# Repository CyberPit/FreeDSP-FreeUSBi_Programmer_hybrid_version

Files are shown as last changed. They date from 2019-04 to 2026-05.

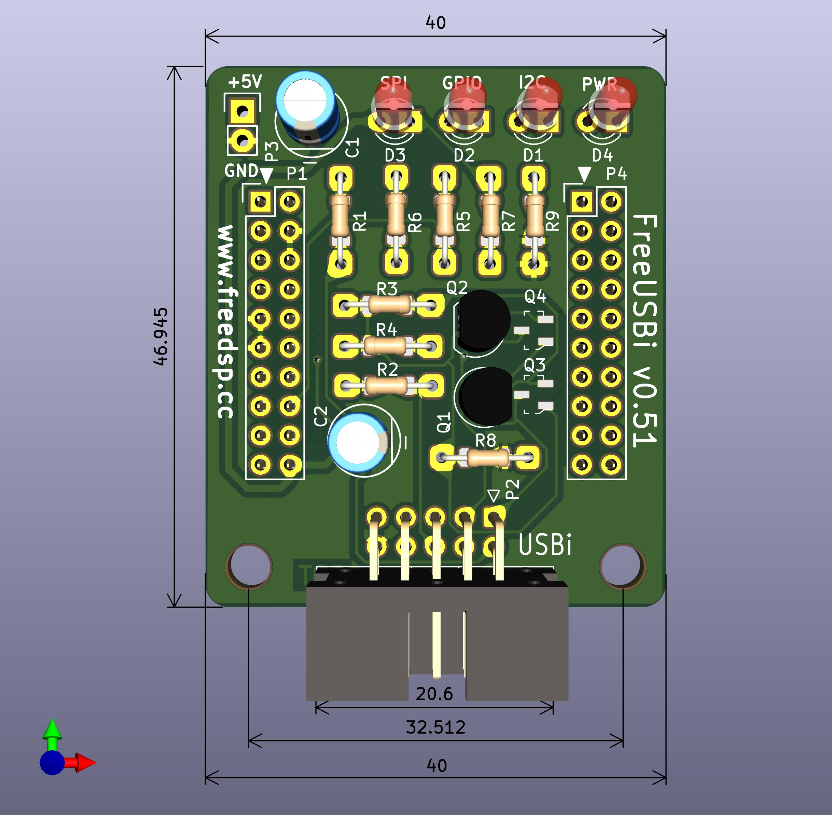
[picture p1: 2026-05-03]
Photo/FreeUSBi_0V51_TOP.jpg

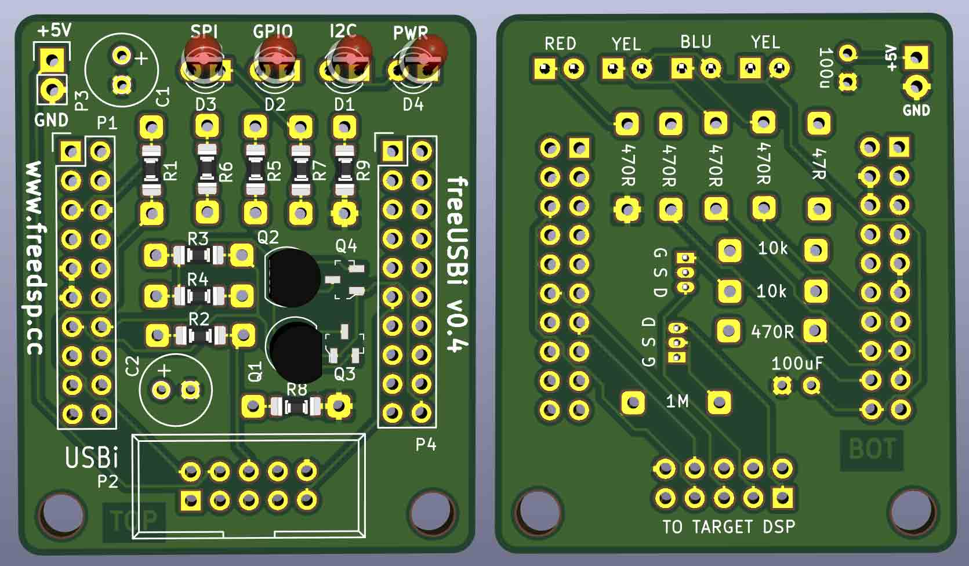
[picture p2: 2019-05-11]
Photo/FreeUSBi_0v4_Image.jpg

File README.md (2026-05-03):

# FreeDSP-FreeUSBi_Programmer_hybrid_version　　

FreeUSBi

This is another PCB layout design of FreeUSBi.  
Component Layout had changed, Voltage-shifter design changed, selectable parts type capability (SMD or TH)
Please see the images in the "Photo" directory for differences.  
  
## Issue found on some CY7C68013A boards.
Some CY7C68013A boards can not boot when connected to a FreeUSBi board. The reason is that the SDA line of the I2C bus voltage dropped during the boot sequence. The Voltage-Shifter circuit control line and I2C pull-up circuit were not tied to 3.3V because the uP has not run yet. So, the version 0.5 design connects them to a regulated 3.3V line. According to this change, the I2C line is pulled up to 3.3V anytime a USB is connected.  
  
## For Windows 10 users, Info:
Some machines were not able to run the official FreeUSBi driver.  
But a few machines have succeeded in installing & running with the 3eAudio version FreeUSBi driver (Located at https://www.3e-audio.com/dsp/adau1701-2in4out/)

# License
This work and all other materials under https://github.com/freeDSP are licensed under a Creative Commons Attribution Share-Alike 4.0 license. This allows for both personal and commercial derivative works, as long as they credit freeDSP and release their designs under the same license.

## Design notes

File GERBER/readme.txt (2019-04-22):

Here is another version PCB Gerber file of FreeUSBi

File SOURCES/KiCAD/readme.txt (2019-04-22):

Here is another version of FreeUSBi.
- Same Function
- New Layout PCB
- Selectable SMD/TH resisitors

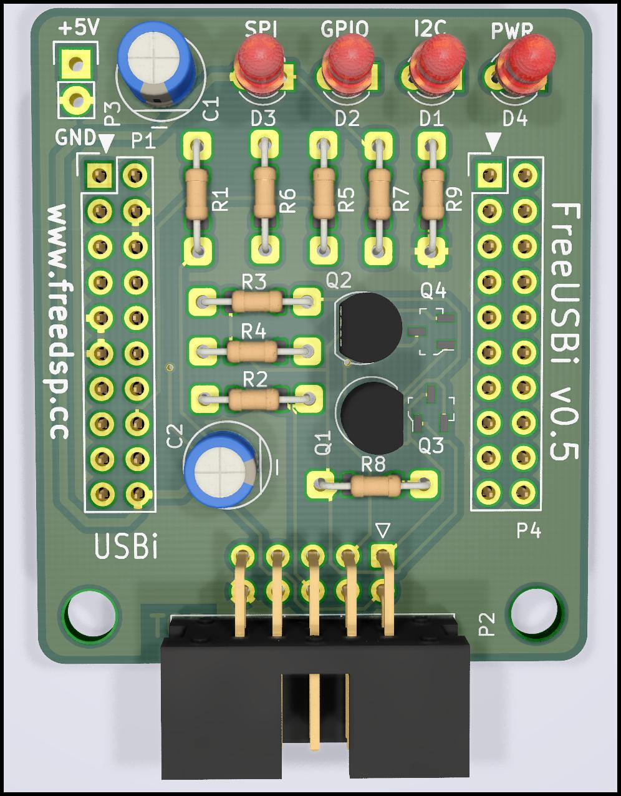
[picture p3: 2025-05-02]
Photo/FreeUSBi_0v5_TopView.jpg

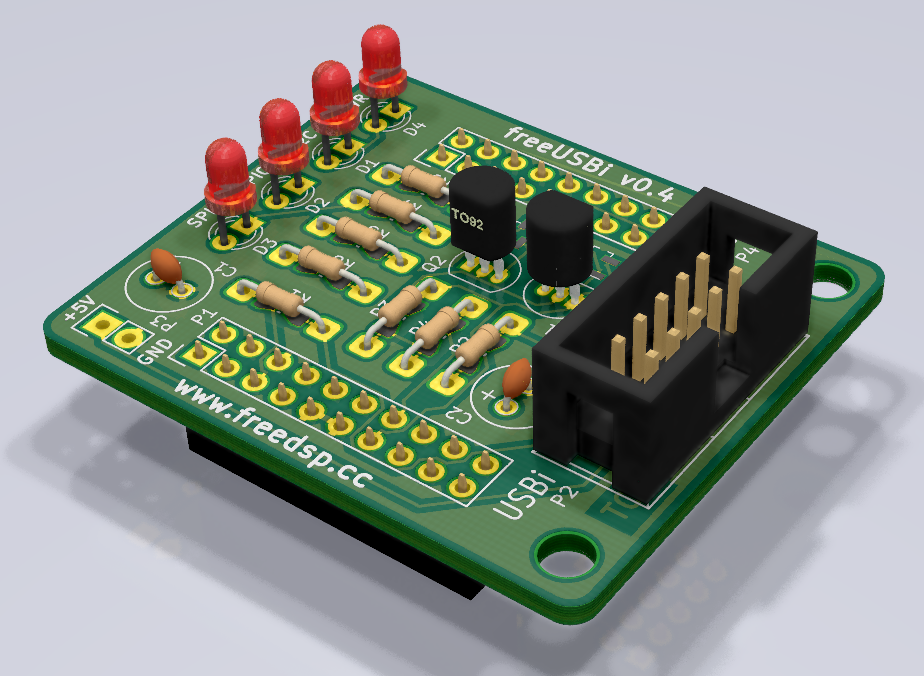
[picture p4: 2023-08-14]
Photo/FreeUSBi_3D.png

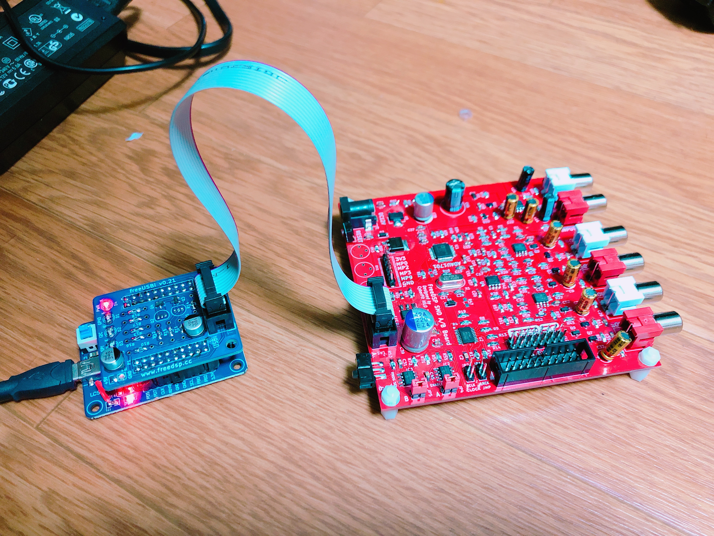
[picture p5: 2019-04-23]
Photo/FreeUSBi_Programmer0v21.JPG

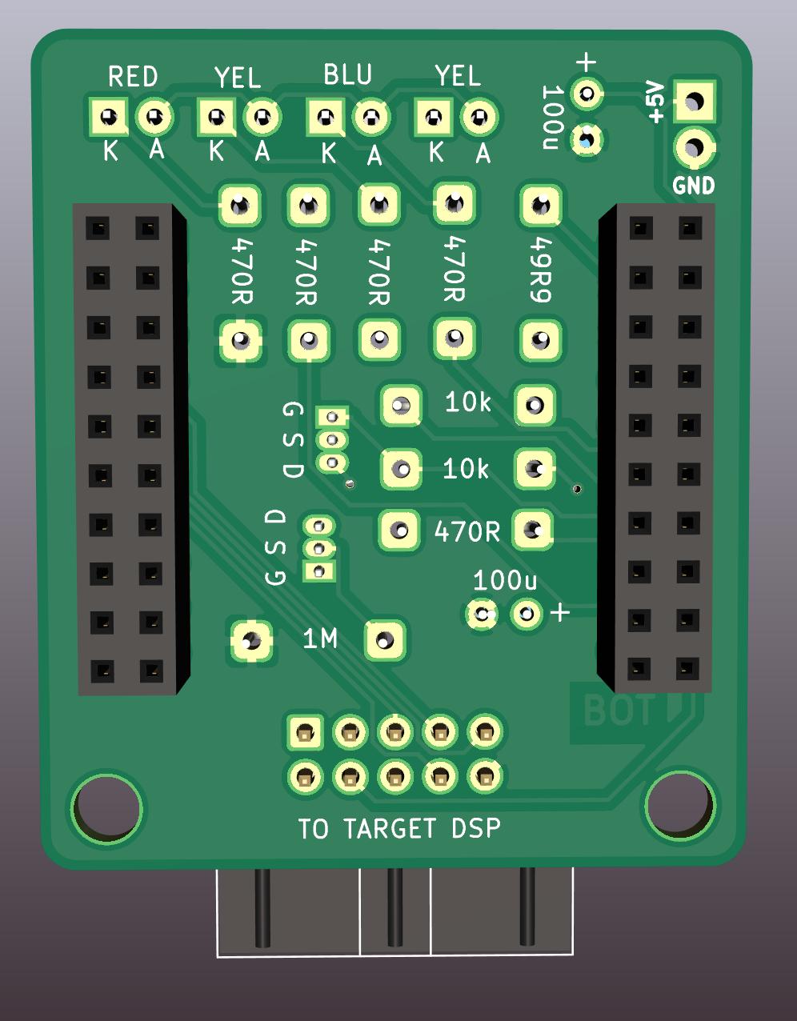
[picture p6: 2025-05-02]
Photo/FreeUSBi_0v5_BottomView.jpg

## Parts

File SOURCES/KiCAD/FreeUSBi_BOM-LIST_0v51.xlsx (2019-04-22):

Reference | Value | Footprint | Datasheet | Category | DK_Datasheet_Link | DK_Detail_Page | Description | Digi-Key_PN | Family | MPN | Manufacturer | Status
C1 | 100u | Capacitors_Elko_ThroughHole:Elko_vert_11.2x6.3mm_RM2.5_CopperClear
C2 | 100u | Capacitors_Elko_ThroughHole:Elko_vert_11.2x6.3mm_RM2.5_CopperClear
D1 | LED | LEDs:LED-3MM
D2 | LED | LEDs:LED-3MM
D3 | LED | LEDs:LED-3MM
D4 | LED | LEDs:LED-3MM
P1 | CONN_02X10 | fdsp_pinheader:Pin_Header_Straight_2x10
P2 | CONN_02X05 | Connectors_IDC:IDC-Header_2x05_Pitch2.54mm_Straight
P3 | CONN_01X02 | fdsp_pinheader:Pin_Header_Straight_1x02
P4 | CONN_02X10 | fdsp_pinheader:Pin_Header_Straight_2x10
Q1 | Q_NMOS_DGS | TO_SOT_Packages_THT:TO-92_Inline_Narrow_Oval
Q2 | Q_NMOS_DGS | TO_SOT_Packages_THT:TO-92_Inline_Narrow_Oval
Q3 | 2N7002 | digikey-footprints:SOT-23-3 | https://www.fairchildsemi.com/datasheets/2N/2N7000.pdf | Discrete Semiconductor Products | https://www.fairchildsemi.com/datasheets/2N/2N7000.pdf | /product-detail/en/on-semiconductor/2N7002/2N7002NCT-ND/244664 | MOSFET N-CH 60V 115MA SOT-23 | 2N7002NCT-ND | Transistors - FETs, MOSFETs - Single | 2N7002 | ON Semiconductor | Active
Q4 | 2N7002 | digikey-footprints:SOT-23-3 | https://www.fairchildsemi.com/datasheets/2N/2N7000.pdf | Discrete Semiconductor Products | https://www.fairchildsemi.com/datasheets/2N/2N7000.pdf | /product-detail/en/on-semiconductor/2N7002/2N7002NCT-ND/244664 | MOSFET N-CH 60V 115MA SOT-23 | 2N7002NCT-ND | Transistors - FETs, MOSFETs - Single | 2N7002 | ON Semiconductor | Active
R1 | 49R9 | Resistors_THT:R_Axial_DIN0204_L3.6mm_D1.6mm_P7.62mm_Horizontal
R10 | 49R9 | Resistors_SMD:R_0805_HandSoldering
R11 | 470R | Resistors_SMD:R_0805_HandSoldering
R12 | 10k | Resistors_SMD:R_0805_HandSoldering
R13 | 470R | Resistors_SMD:R_0805_HandSoldering
R14 | 1M | Resistors_SMD:R_0805_HandSoldering
R15 | 10k | Resistors_SMD:R_0805_HandSoldering
R16 | 470R | Resistors_SMD:R_0805_HandSoldering
R17 | 470R | Resistors_SMD:R_0805_HandSoldering
R18 | 470R | Resistors_SMD:R_0805_HandSoldering
R2 | 470R | Resistors_THT:R_Axial_DIN0204_L3.6mm_D1.6mm_P7.62mm_Horizontal
R3 | 10k | Resistors_THT:R_Axial_DIN0204_L3.6mm_D1.6mm_P7.62mm_Horizontal
R4 | 10k | Resistors_THT:R_Axial_DIN0204_L3.6mm_D1.6mm_P7.62mm_Horizontal
R5 | 470R | Resistors_THT:R_Axial_DIN0204_L3.6mm_D1.6mm_P7.62mm_Horizontal
R6 | 470R | Resistors_THT:R_Axial_DIN0204_L3.6mm_D1.6mm_P7.62mm_Horizontal
R7 | 470R | Resistors_THT:R_Axial_DIN0204_L3.6mm_D1.6mm_P7.62mm_Horizontal
R8 | 1M | Resistors_THT:R_Axial_DIN0204_L3.6mm_D1.6mm_P7.62mm_Horizontal
R9 | 470R | Resistors_THT:R_Axial_DIN0204_L3.6mm_D1.6mm_P7.62mm_Horizontal

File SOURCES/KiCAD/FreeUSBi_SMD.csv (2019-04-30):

Reference | Qty. | Value | SMD/TH | Footprint | Shop URL
P1, P4 | 2 | CONN_02X10 | COM | Pin_Header_Socker Straight_2x10 | http://akizukidenshi.com/catalog/g/gC-00083/
P2 | 1 | CONN_02X05 | COM | IDC-Header_2x05_Pitch2.54mm_Straight | http://akizukidenshi.com/catalog/g/gC-12664/
D1 | 1 | LED | COM | LEDs:LED-3MM
D2 | 1 | LED | COM | LEDs:LED-3MM
D3 | 1 | LED | COM | LEDs:LED-3MM
D4 | 1 | LED | COM | LEDs:LED-3MM
C1ÅAC2 | 2 | 100u | COM | Capacitors_Elko_ThroughHole:Elko_vert_11.2x6.3mm_RM2.5_CopperClear | http://akizukidenshi.com/catalog/g/gP-05002/
P3 | 1 | CONN_01X02 | NOPOP | fdsp_pinheader:Pin_Header_Straight_1x02 | Directly Jumper wire conncetion to the Ez-USB FX2LP Board 5V
Q3, Q4 | 2 | 2N7002 | SMD | digikey-footprints:SOT-23-3 | http://akizukidenshi.com/catalog/g/gI-04256/
R10 | 1 | 51R | SMD | Resistors_SMD:R_0805_HandSoldering
R11, R13, R16, R17, R18 | 5 | 470R | SMD | Resistors_SMD:R_0805_HandSoldering
R14 | 1 | 1M | SMD | Resistors_SMD:R_0805_HandSoldering
R12, R15 | 2 | 10k | SMD | Resistors_SMD:R_0805_HandSoldering
10P IDC Cable Assy. | 1 | - | COM | Programming Cable | http://akizukidenshi.com/catalog/g/gC-03796/
Mini USB Cable | 1 | - | COM | USB-A to mini-USB | http://akizukidenshi.com/catalog/g/gC-07606/
Ez-USB FX2LP Board | 1 | - | COM | Various Choice | https://www.amazon.co.jp/SODIAL-%E9%96%8B%E7%99%BA%E3%83%9C%E3%83%BC%E3%83%89USB2-0-EZ-USB-FX2LP-CY7C68013A/dp/B00OCEEIX0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

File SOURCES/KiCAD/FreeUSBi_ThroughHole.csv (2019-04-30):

Reference | Qty. | Value | SMD/TH | Footprint | Shop URL
P1, P4 | 2 | CONN_02X10 | COM | Pin_Header_Socker Straight_2x10 | http://akizukidenshi.com/catalog/g/gC-00083/
P2 | 1 | CONN_02X05 | COM | IDC-Header_2x05_Pitch2.54mm_Straight | http://akizukidenshi.com/catalog/g/gC-12664/
D1 | 1 | LED | COM | LEDs:LED-3MM
D2 | 1 | LED | COM | LEDs:LED-3MM
D3 | 1 | LED | COM | LEDs:LED-3MM
D4 | 1 | LED | COM | LEDs:LED-3MM
C1ÅAC2 | 2 | 100u | COM | Capacitors_Elko_ThroughHole:Elko_vert_11.2x6.3mm_RM2.5_CopperClear
P3 | 1 | CONN_01X02 | NOPOP | fdsp_pinheader:Pin_Header_Straight_1x02 | Directly Jumper wire conncetion to the Ez-USB FX2LP Board 5V
Q1, Q2 | 2 | 2N7000 | TH | TO_SOT_Packages_THT:TO-92_Inline_Narrow_Oval | http://akizukidenshi.com/catalog/g/gI-13045/
R1 | 1 | 51R | TH | Resistors_THT:R_Axial_DIN0204_L3.6mm_D1.6mm_P7.62mm_Horizontal | Free Size (1.6mm x 0.8mm, 2.0mm x 1.25mm, 3.2mm x 1.6mm)
R2, R5, R6, R7, R9 | 5 | 470R | TH | Resistors_THT:R_Axial_DIN0204_L3.6mm_D1.6mm_P7.62mm_Horizontal | Free Size (1.6mm x 0.8mm, 2.0mm x 1.25mm, 3.2mm x 1.6mm)
R8 | 1 | 1M | TH | Resistors_THT:R_Axial_DIN0204_L3.6mm_D1.6mm_P7.62mm_Horizontal | Free Size (1.6mm x 0.8mm, 2.0mm x 1.25mm, 3.2mm x 1.6mm)
R3, R4 | 2 | 10k | TH | Resistors_THT:R_Axial_DIN0204_L3.6mm_D1.6mm_P7.62mm_Horizontal | Free Size (1.6mm x 0.8mm, 2.0mm x 1.25mm, 3.2mm x 1.6mm)
10P IDC Cable Assy. | 1 | - | COM | Programming Cable | http://akizukidenshi.com/catalog/g/gC-03796/
Mini USB Cable | 1 | - | COM | USB-A to mini-USB | http://akizukidenshi.com/catalog/g/gC-07606/
Ez-USB FX2LP Board | 1 | - | COM | Various Choice | https://www.amazon.co.jp/SODIAL-%E9%96%8B%E7%99%BA%E3%83%9C%E3%83%BC%E3%83%89USB2-0-EZ-USB-FX2LP-CY7C68013A/dp/B00OCEEIX0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

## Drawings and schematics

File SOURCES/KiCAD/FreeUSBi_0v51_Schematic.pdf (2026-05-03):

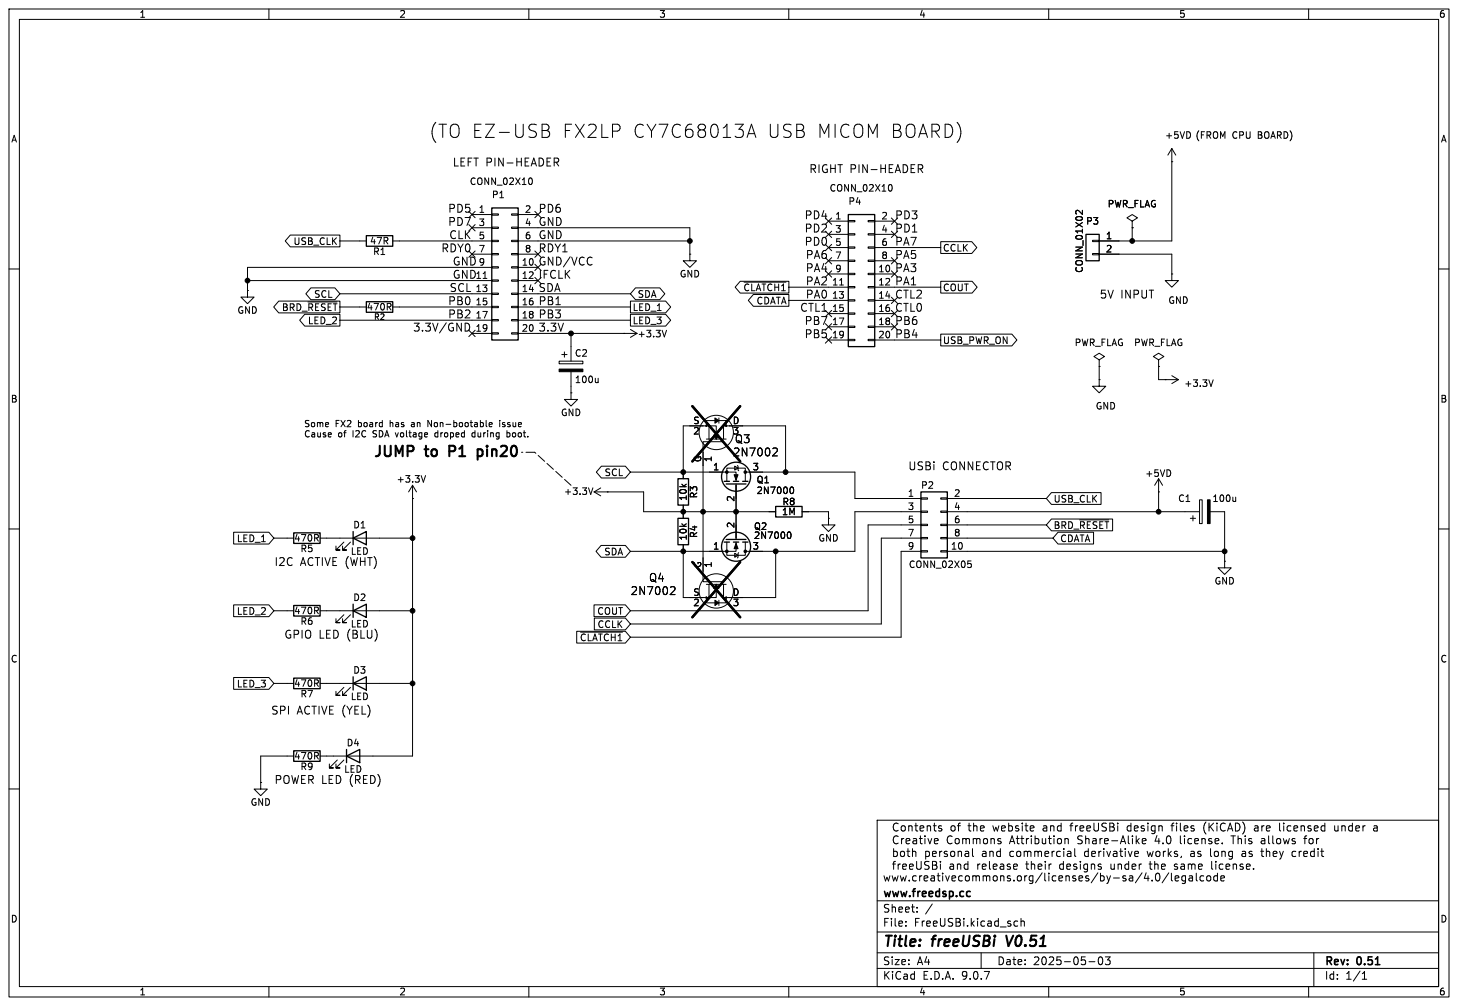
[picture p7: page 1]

(TO EZ-USB FX2LP CY7C68013A USB MICOM BOARD) LEFT PIN-HEADER
2N7000 GND

freeUSBi and release their designs under the same license.
www.creativecommons.org/licenses/by-sa/4.0/legalcode
File: FreeUSBi.kicad_sch Sheet: / www.freedsp.cc

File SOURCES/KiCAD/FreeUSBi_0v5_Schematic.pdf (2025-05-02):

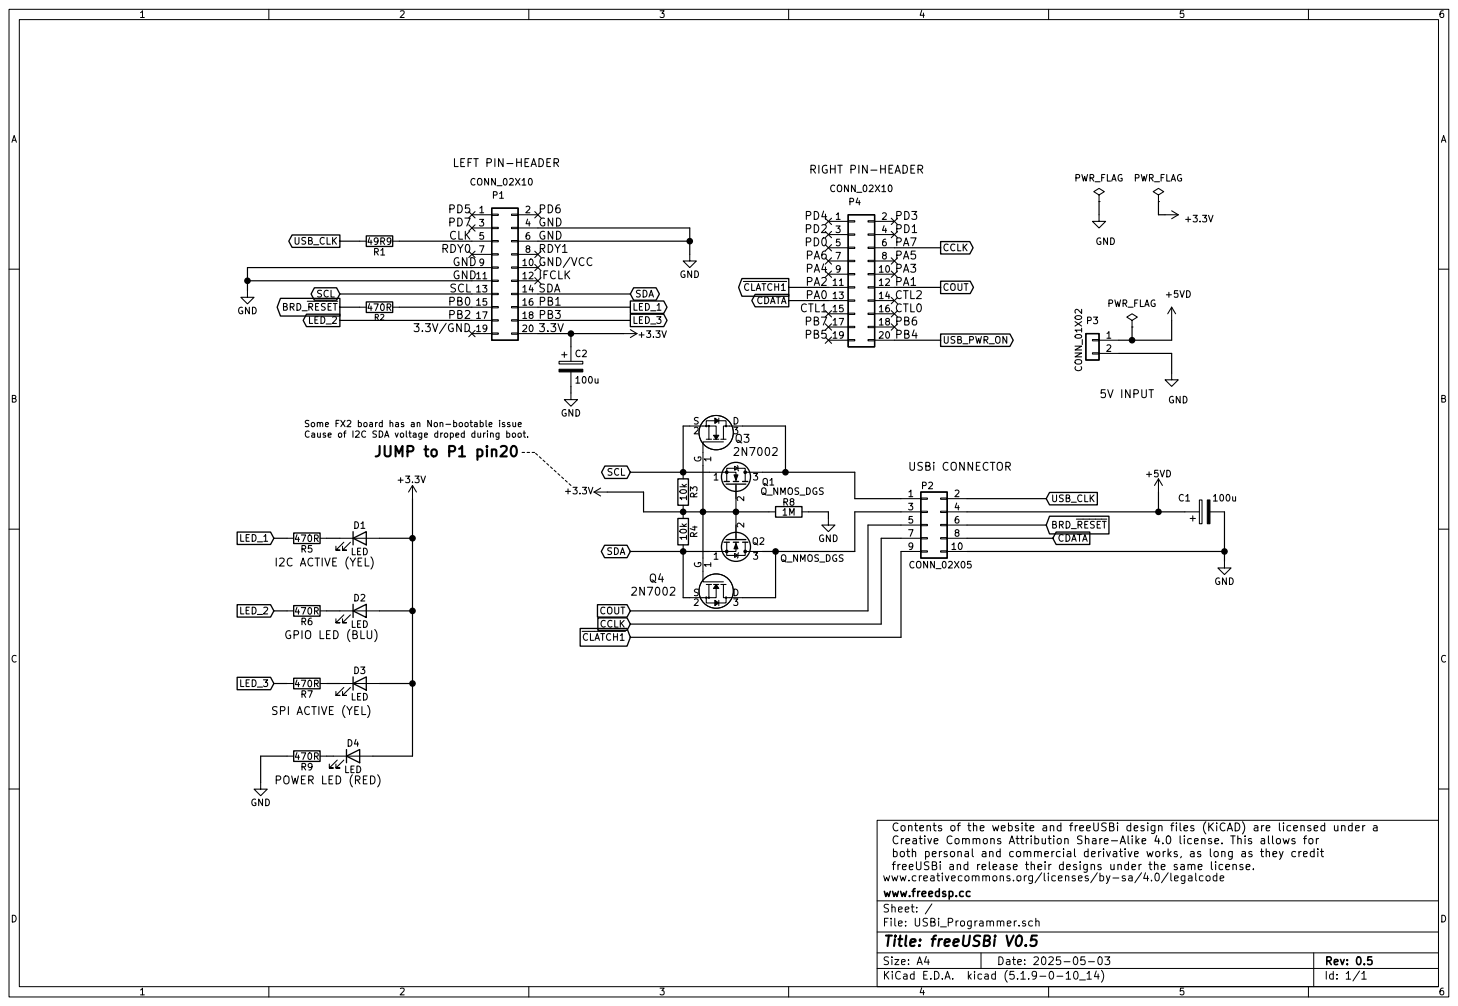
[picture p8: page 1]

PWR_FLAG
COUT CCLK USBi CONNECTOR

Some FX2 board has an Non-bootable issue Cause of I2C SDA voltage droped during boot.

Contents of the website and freeUSBi design files (KiCAD) are licensed under a
Creative Commons Attribution Share-Alike 4.0 license. This allows for
both personal and commercial derivative works, as long as they credit
freeUSBi and release their designs under the same license.
www.creativecommons.org/licenses/by-sa/4.0/legalcode
File: USBi_Programmer.sch Sheet: / www.freedsp.cc

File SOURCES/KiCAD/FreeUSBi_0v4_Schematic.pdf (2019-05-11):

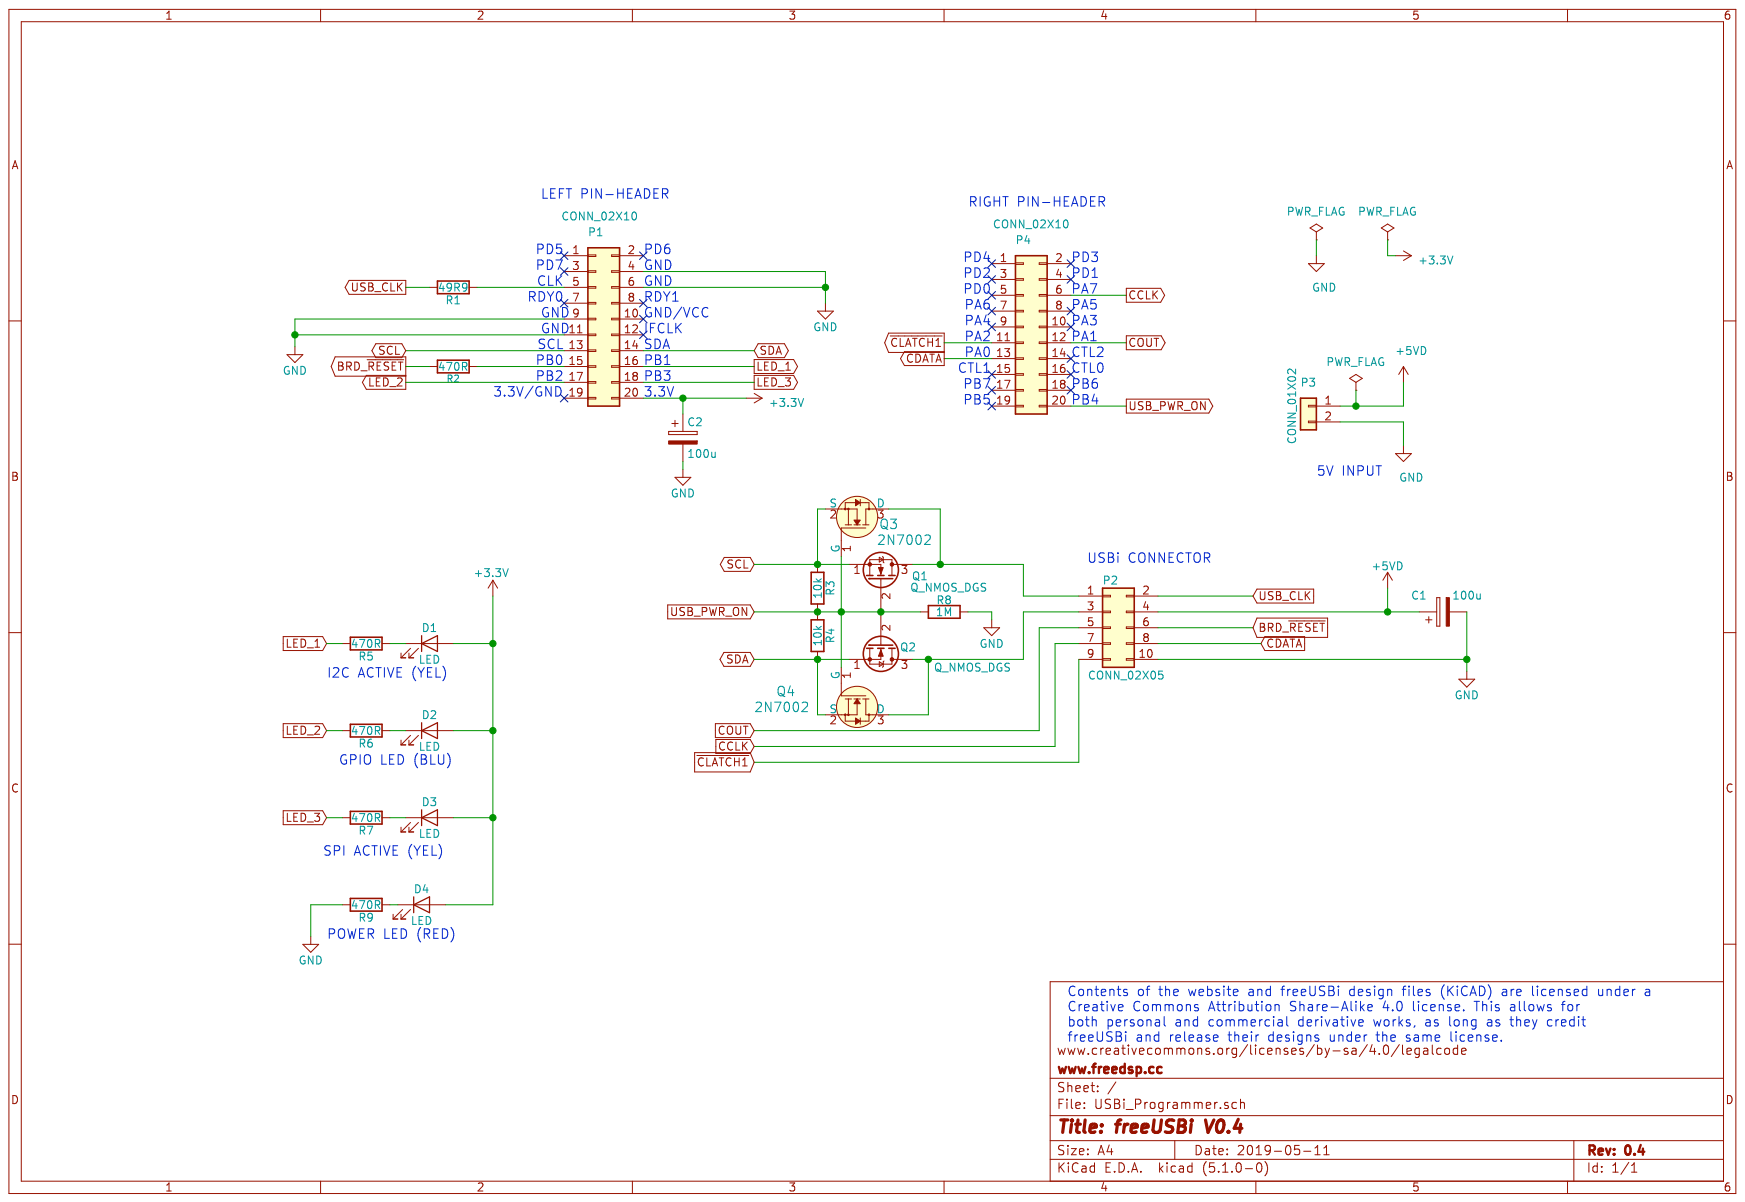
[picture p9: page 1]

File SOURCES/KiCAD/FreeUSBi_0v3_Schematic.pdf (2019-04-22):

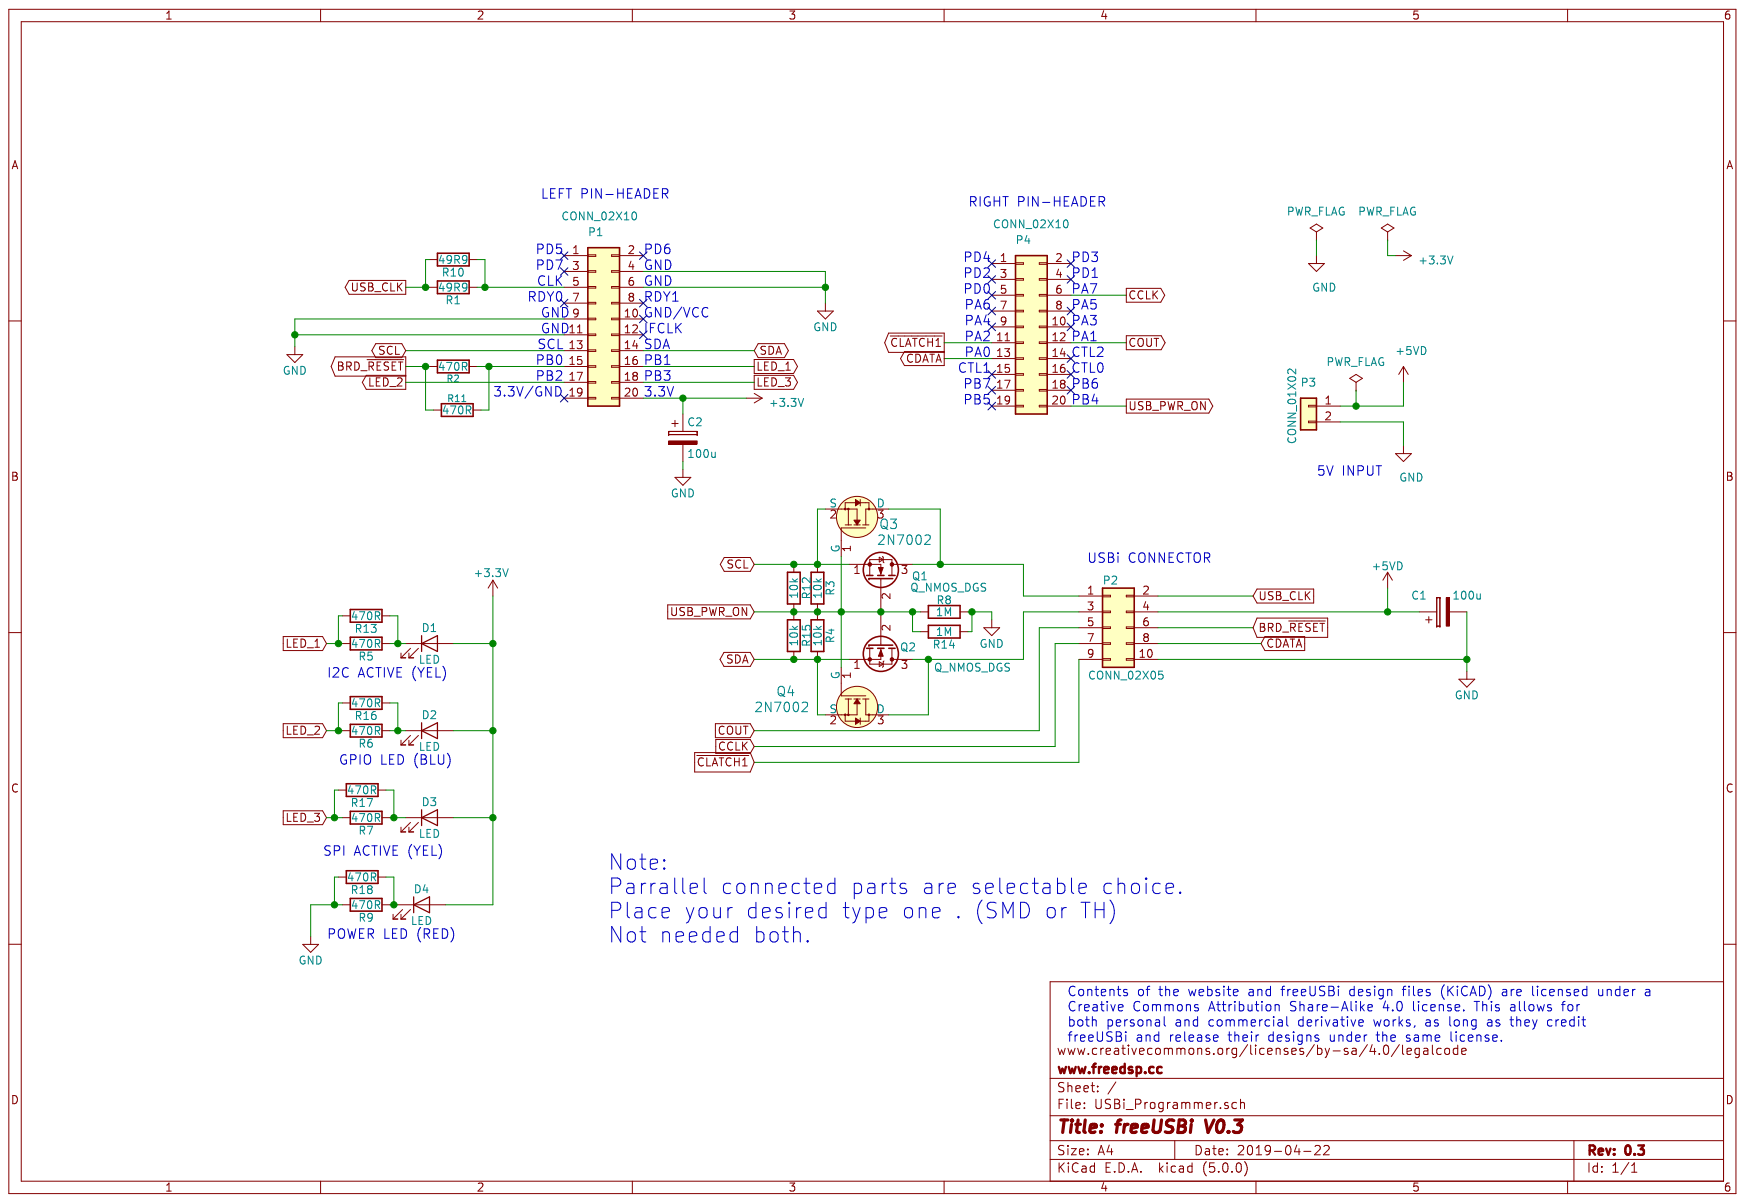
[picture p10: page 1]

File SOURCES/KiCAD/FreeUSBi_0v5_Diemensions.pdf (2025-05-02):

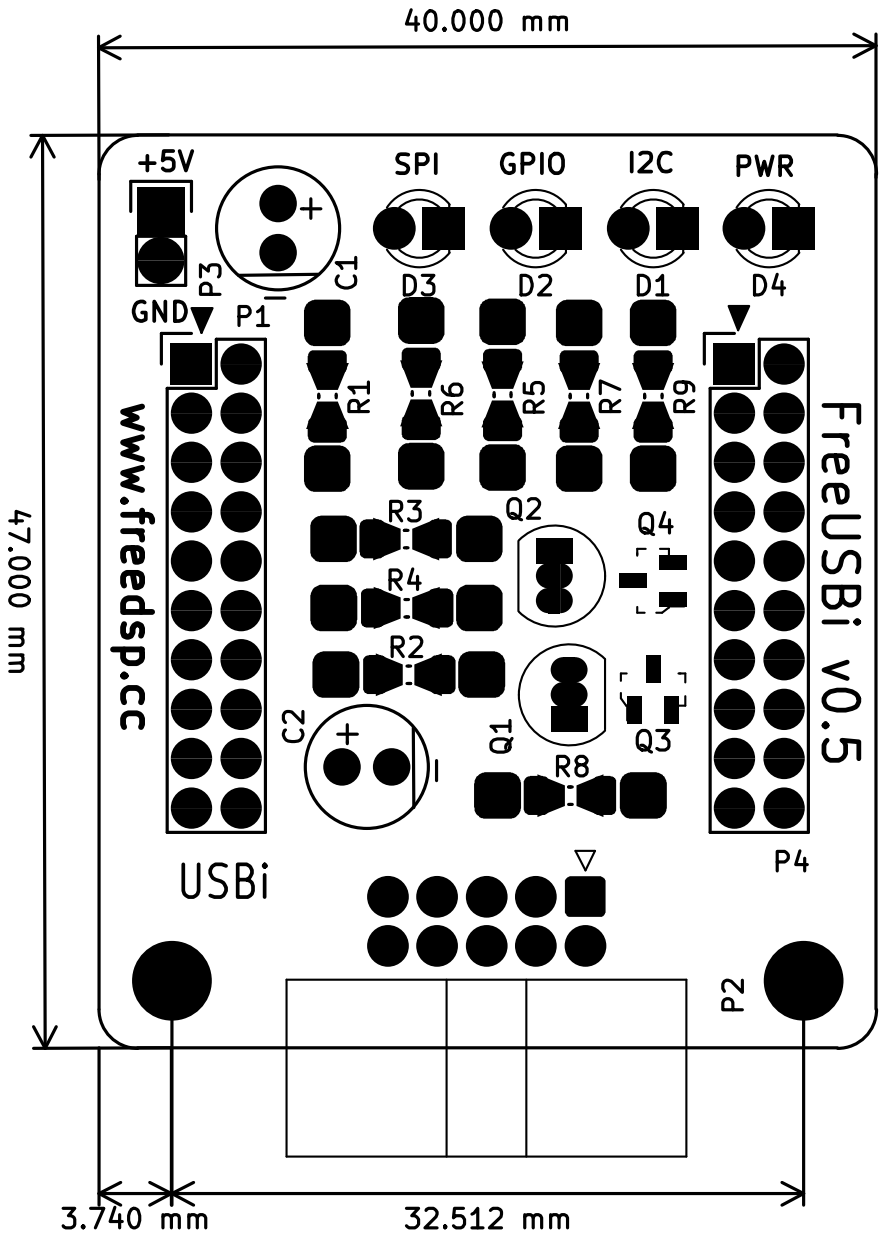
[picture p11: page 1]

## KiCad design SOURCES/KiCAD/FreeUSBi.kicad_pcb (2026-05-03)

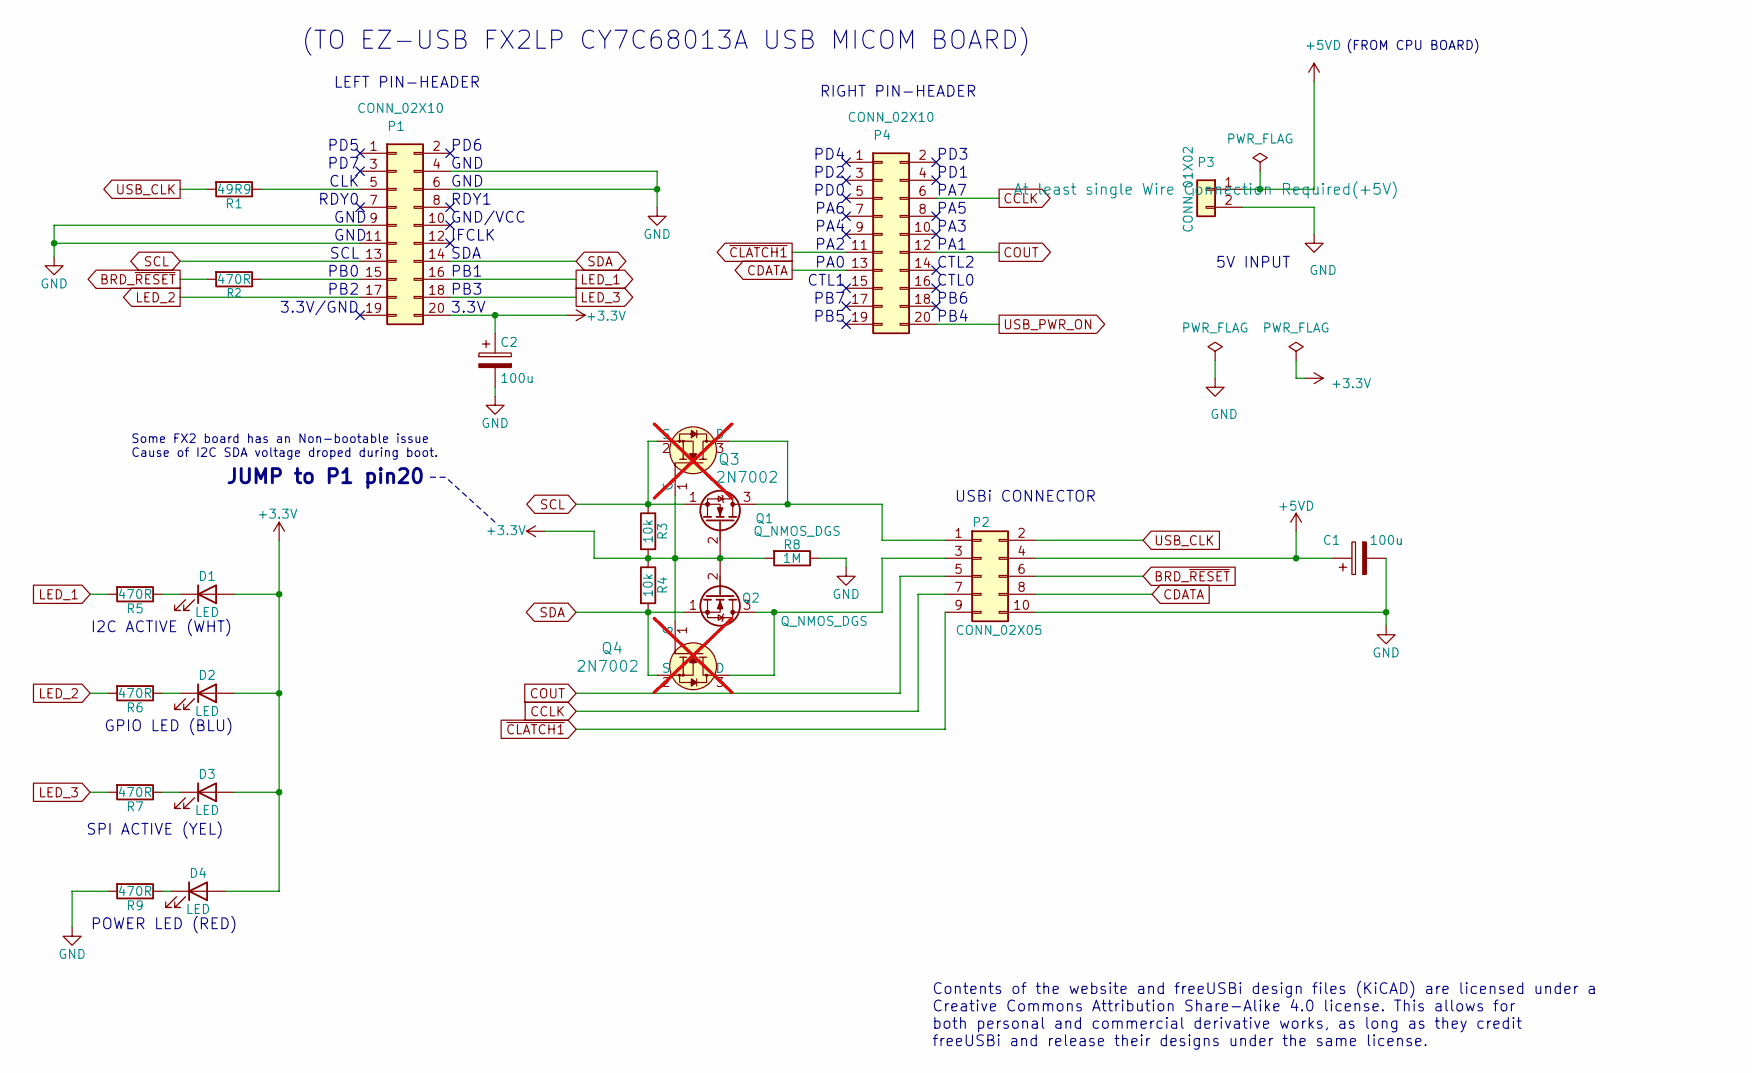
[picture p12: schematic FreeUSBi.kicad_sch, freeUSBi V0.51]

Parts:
C1, C2: 100u; Elko_vert_11.2x6.3mm_RM2.5_CopperClear
D1, D2, D3, D4: LED; LED_D3.0mm
P1, P4: CONN_02X10; Pin_Header_Straight_2x10
P2: CONN_02X05; IDC_Header_Straight_10pins
P3: CONN_01X02; Pin_Header_Straight_1x02
Q1, Q2: Q_NMOS_DGS; TO-92_Inline_Narrow_Oval
Q3, Q4: 2N7002; SOT-23-3; MPN 2N7002; Digi-Key_PN 2N7002NCT-ND; not fitted
R1: 49R9; Resistor_SMD+THTuniversal_0603to0805_RM7.5_HandSoldering_Re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
R2, R5, R6, R7, R9: 470R; Resistor_SMD+THTuniversal_0603to0805_RM7.5_HandSoldering_Re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
R3, R4: 10k; Resistor_SMD+THTuniversal_0603to0805_RM7.5_HandSoldering_Re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
R8: 1M; Resistor_SMD+THTuniversal_0603to0805_RM7.5_HandSoldering_Re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

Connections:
+5VD: C1.1, P2.4, P3.1
BRD_~RESET: P2.6, R2.2
CCLK: P2.7, P4.6
CDATA: P2.8, P4.13
COUT: P2.5, P4.12
GND: C1.2, C2.2, P1.4, P1.6, P1.9, P1.11, P2.10, P3.2, R8.1, R9.2
LED_1: P1.16, R5.2
LED_2: P1.17, R6.2
LED_3: P1.18, R7.2
unnamed: D1.1 (K), R5.1
unnamed: D2.1 (K), R6.1
unnamed: D3.1 (K), R7.1
unnamed: D4.1 (K), R9.1
unnamed: P1.5, R1.1
unnamed: P1.15, R2.1
unnamed: P2.1, Q1.3 (D), Q3.3 (D)
unnamed: P2.3, Q2.3 (D), Q4.3 (D)
SCL: P1.13, Q1.1 (S), Q3.2 (S), R3.1
SDA: P1.14, Q2.1 (S), Q4.2 (S), R4.2
USB_CLK: P2.2, R1.2
USB_PWR_ON: P4.20
~CLATCH1: P2.9, P4.11

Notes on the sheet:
POWER LED (RED)
IFCLK
Contents of the website and freeUSBi design files (KiCAD) are licensed under a Creative Commons Attribution Share-Alike 4.0 license. This allows for both personal and commercial derivative works, as long as they credit freeUSBi and release their designs under the same license.
PA5
PB4
PD1
PA7
PB1
GND
GND/VCC
RDY0
PA4
3.3V
PB2
I2C ACTIVE (WHT)
CTL2
SCL
3.3V/GND
(TO EZ-USB FX2LP CY7C68013A USB MICOM BOARD)
PD0
PB6
PB5
CTL1
USBi CONNECTOR
PB0
PA1
PA0
PA3
JUMP to P1 pin20
(FROM CPU BOARD)
PD5
PD2
5V INPUT
SDA
SPI ACTIVE (YEL)
PB3
Some FX2 board has an Non-bootable issue Cause of I2C SDA voltage droped during boot.
PA2
PD6
GPIO LED (BLU)

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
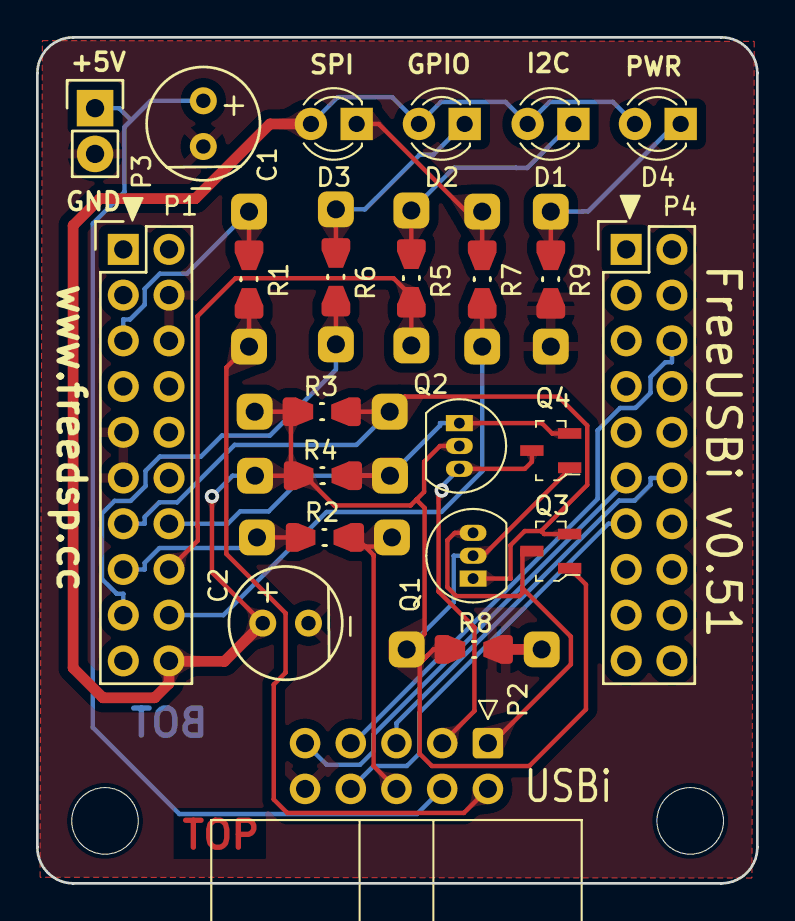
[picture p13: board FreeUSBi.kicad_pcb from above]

Board: 2 copper layers, 40.0 x 47.0 mm, 23 parts (0 on the bottom side), 22 nets.

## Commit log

2025-05-02 Gerber and Drill File
2025-05-02 Verion 0.5 update Release
    [USBi_Programmer.kicad_pcb, USBi_Programmer.sch]
